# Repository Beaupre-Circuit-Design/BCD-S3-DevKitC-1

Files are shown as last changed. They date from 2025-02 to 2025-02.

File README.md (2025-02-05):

# BCD-S3-DevKitC-1

ESP32-S3-WROOM-1-N16R8 Development Board

## Description

An ESP32-S3 development board based on Espressif's ESP32-S3-DevKitC-1.

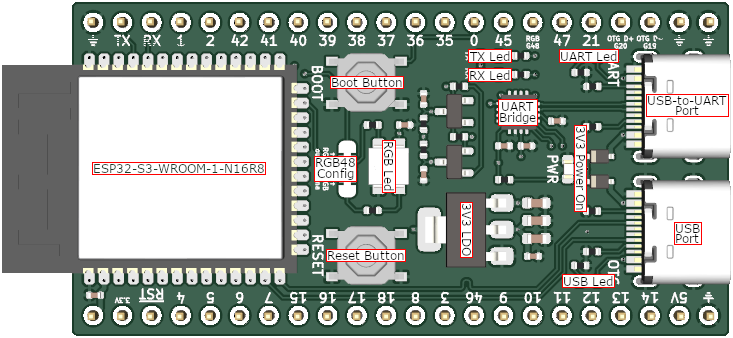
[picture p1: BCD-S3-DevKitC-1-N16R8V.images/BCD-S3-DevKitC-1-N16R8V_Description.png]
Board Description


|Key Component |Description |
|---|---|
|ESP32-S3-WROOM-1-N16R8|ESP32-S3R8 with 3.3V, 8 MB Octal PSRAM die inside, 16 MB Quad SPI flash, PCB antenna.[^1]|
|3V3 LDO |Power regulator that converts a 5 V supply into a 3.3 V output.|
|Boot Button |Holding down Boot and then pressing Reset initiates Firmware Download mode for downloading firmware through the serial port.|
|Reset Button |Press this button to restart the system.|
|RGB48 Config |Configuration options for the RGB Led / GPIO 48.|
|USB-to-Uart Port |A Micro-USB port used for power supply to the board, for flashing applications to the chip, as well as for communication with the chip via the on-board USB-to-UART bridge.|
|USB Port |ESP32-S3 full-speed USB OTG interface, compliant with the USB 1.1 specification. The interface is used for power supply to the board, for flashing applications to the chip, for communication with the chip using USB 1.1 protocols, as well as for JTAG debugging.|
|UART Led |Indicate if the USB-to-UART port is connected.|
|USB Led |Indicate if the USB port is connected.|
|3V3 Power On |Indicate if the 3V3 bus is powered.|
|TX Led |Indicate if the serial bus is transmitting.|
|RX Led |Indicate if the serial bus is receiving.|
|RGB Led |Addressable RGB LED, driven by GPIO48.|

[^1]: GPIO35, GPIO36 and GPIO37 are used for the internal communication between ESP32-S3 and SPI flash/PSRAM memory, thus not available for external use.

## Pinout

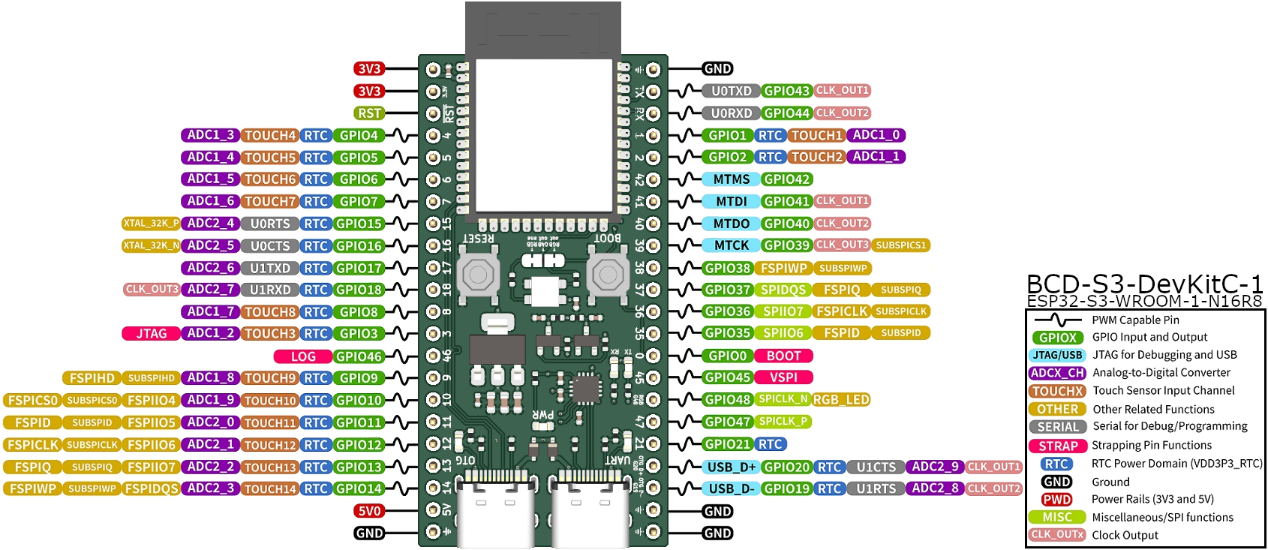
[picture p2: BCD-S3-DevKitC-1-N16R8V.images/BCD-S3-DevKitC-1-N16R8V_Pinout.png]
Board Pinout


## RGB48 Jumper

|Jumper|Effect|
|---|---|
|Default|Default Configuration, RGB48 pin is the output of the RGBLed.|
|Mode 1|RGB48 pin is the output of GPIO48, Led is still active and drive by GPIO48. [^2]|
|Mode 2|RGB48 pin is the output of GPIO48, Led is deactivated. [^2][^3]|

[^2]: If the output of the RGBLed is still needed, a wire can be soldered to the leftmost pad.
[^3]: The RGBLed can still be driven by soldering a wire to the rightmost pad.

## Bulding / Ordering PCB

The [board layout](BCD-S3-DevKitC-1-N16R8V.production/gerber) and [bill of material](BCD-S3-DevKitC-1-N16R8V.production/assembly) has been optimised for JLCPCB's capabilities and inventories to minimise cost. The footprint for the ESP32-S3 module has been optimised for hand-soldering since this part alone greatly increase the price of the assembly.

## Version History

* 1.1(2025-02-02)
    * Fix error in RGB48 Jumper.
* 1.0(2025-01-05)
    * Initial Release.

## License

This project is licensed under the [BSD 3-Clause License](LICENSE).

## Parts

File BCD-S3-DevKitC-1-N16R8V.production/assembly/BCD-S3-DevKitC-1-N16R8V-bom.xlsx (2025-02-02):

Reference | Value | Datasheet | Footprint | Qty | DNP | JLCPCB | Manufacturer | PartNumber | Description
C1,C3,C9,C11 | 1uF | https://www.lcsc.com/datasheet/lcsc_datasheet_2304140030_Samsung-Electro-Mechanics-CL05A105KA5NQNC_C52923.pdf | BCD-S3-DevKitC-1-N16R8V:C_0402_1005Metric | 4 | False | C52923 | Samsung Electro-Mechanics | CL05A105KA5NQNC | 25V 1uF X5R ±10% 0402 Multilayer Ceramic Capacitors MLCC - SMD/SMT ROHS
C2,C4,C5,C10 | 100nF | https://www.lcsc.com/datasheet/lcsc_datasheet_2304140030_Samsung-Electro-Mechanics-CL05B104KO5NNNC_C1525.pdf | BCD-S3-DevKitC-1-N16R8V:C_0402_1005Metric | 4 | False | C1525 | Samsung Electro-Mechanics | CL05B104KO5NNNC | 16V 100nF X7R ±10% 0402 Multilayer Ceramic Capacitors MLCC - SMD/SMT ROHS
C6,C7,C8 | 10uF | https://www.lcsc.com/datasheet/lcsc_datasheet_2304140030_Samsung-Electro-Mechanics-CL10A106MA8NRNC_C96446.pdf | BCD-S3-DevKitC-1-N16R8V:C_0603_1608Metric | 3 | False | C96446 | Samsung Electro-Mechanics | CL10A106MA8NRNC | 25V 10uF X5R ±20% 0603 Multilayer Ceramic Capacitors MLCC - SMD/SMT ROHS
D1,D2 | 1N5819WS | https://www.lcsc.com/datasheet/lcsc_datasheet_2409300937_Guangdong-Hottech-1N5819WS_C191023.pdf | BCD-S3-DevKitC-1-N16R8V:D_SOD-323 | 2 | False | C191023 | Guangdong Hottech | 1N5819WS | 40V 600mV@1A 1A SOD-323 Schottky Diodes ROHS
D3,D4,D5,D7,D8 | RED | https://www.lcsc.com/datasheet/lcsc_datasheet_1810231112_Hubei-KENTO-Elec-KT-0603R_C2286.pdf | BCD-S3-DevKitC-1-N16R8V:LED_0603_1608Metric | 5 | False | C2286 | Hubei KENTO Elec | KT-0603R | Red 0603 LED Indication - Discrete ROHS
D6 | SK6812MINI-HS | https://www.lcsc.com/datasheet/lcsc_datasheet_2412101523_OPSCO-Optoelectronics-SK6812MINI-HS_C2922787.pdf | BCD-S3-DevKitC-1-N16R8V:SK6812MINI-HS | 1 | False | C2922787 | OPSCO Optoelectronics | SK6812MINI-HS | SMD,3.5x3.7mm RGB LEDs(Built-in IC) ROHS
Q1,Q2 | SS8050 | https://www.lcsc.com/datasheet/lcsc_datasheet_2303221100_Jiangsu-Changjing-Electronics-Technology-Co---Ltd--SS8050-RANGE-200-350_C2150.pdf | BCD-S3-DevKitC-1-N16R8V:SOT-23 | 2 | False | C2150 | Jiangsu Changjing Electronics Technology Co., Ltd. | SS8050(RANGE:200-350) | General Purpose NPN Transistor, 1.5A Ic, 25V Vce, SOT-23
R1,R2,R3,R4 | 5.1kΩ | https://www.lcsc.com/datasheet/lcsc_datasheet_2206010045_UNI-ROYAL-Uniroyal-Elec-0402WGF5101TCE_C25905.pdf | BCD-S3-DevKitC-1-N16R8V:R_0402_1005Metric | 4 | False | C25905 | UNI-ROYAL(Uniroyal Elec) | 0402WGF5101TCE | 62.5mW Thick Film Resistors 50V ±100ppm/℃ ±1% 5.1kΩ 0402 Chip Resistor - Surface Mount ROHS
R5,R6,R11,R12,R13,R14,R15 | 510Ω | https://www.lcsc.com/datasheet/lcsc_datasheet_2205311900_UNI-ROYAL-Uniroyal-Elec-0402WGF5100TCE_C25123.pdf | BCD-S3-DevKitC-1-N16R8V:R_0402_1005Metric | 7 | False | C25123 | UNI-ROYAL(Uniroyal Elec) | 0402WGF5100TCE | 62.5mW Thick Film Resistors 50V ±100ppm/℃ ±1% 510Ω 0402 Chip Resistor - Surface Mount ROHS
R7,R8,R9,R10 | 10kΩ | https://www.lcsc.com/datasheet/lcsc_datasheet_2411221126_UNI-ROYAL-Uniroyal-Elec-0402WGF1002TCE_C25744.pdf | BCD-S3-DevKitC-1-N16R8V:R_0402_1005Metric | 4 | False | C25744 | UNI-ROYAL(Uniroyal Elec) | 0402WGF1002TCE | 62.5mW Thick Film Resistors 50V ±100ppm/℃ ±1% 10kΩ 0402 Chip Resistor - Surface Mount ROHS
SW1 | BOOT | https://www.lcsc.com/datasheet/lcsc_datasheet_2304140030_XKB-Connection-TS-1187A-B-A-B_C318884.pdf | BCD-S3-DevKitC-1-N16R8V:SW_Push_1P1T_XKB_TS-1187A | 1 | False | C318884 | XKB Connection | TS-1187A-B-A-B | None Without 50mA 5.1mm 100000 Times 160gf 12V 5.1mm 1.5mm Round Button Standing paste SPST SMD Tactile Switches ROHS
SW2 | RESET | https://www.lcsc.com/datasheet/lcsc_datasheet_2304140030_XKB-Connection-TS-1187A-B-A-B_C318884.pdf | BCD-S3-DevKitC-1-N16R8V:SW_Push_1P1T_XKB_TS-1187A | 1 | True | C318884 | XKB Connection | TS-1187A-B-A-B | None Without 50mA 5.1mm 100000 Times 160gf 12V 5.1mm 1.5mm Round Button Standing paste SPST SMD Tactile Switches ROHS
U1 | ESP32-S3-WROOM-1 | https://www.lcsc.com/datasheet/lcsc_datasheet_2411121101_Espressif-Systems-ESP32-S3-WROOM-1-N16R8_C2913202.pdf | BCD-S3-DevKitC-1-N16R8V:ESP32-S3-WROOM-1 | 1 | False | C2913202 | Espressif Systems | ESP32-S3-WROOM-1-N16R8 | RF Module, ESP32-S3 SoC, Wi-Fi 802.11b/g/n, Bluetooth, BLE, 32-bit, 3.3V, onboard antenna, SMD
U2 | AMS1117-3.3 | https://www.lcsc.com/datasheet/lcsc_datasheet_2304140030_Advanced-Monolithic-Systems-AMS1117-3-3_C6186.pdf | BCD-S3-DevKitC-1-N16R8V:SOT-223-3_TabPin2 | 1 | False | C6186 | Advanced Monolithic Systems | AMS1117-3.3 | 1A Low Dropout regulator, positive, 3.3V fixed output, SOT-223
U3 | CH343P | https://www.lcsc.com/datasheet/lcsc_datasheet_2403131129_WCH-Jiangsu-Qin-Heng-CH343P_C2846043.pdf | BCD-S3-DevKitC-1-N16R8V:QFN-16-1EP_3x3mm_P0.5mm_EP1.7x1.7mm | 1 | False | C2846043 | WCH(Jiangsu Qin Heng) | CH343P | USB serial converter, UART, TQFN-16-EP
USB1 | UART | https://www.lcsc.com/datasheet/lcsc_datasheet_2410010003_Korean-Hroparts-Elec-TYPE-C-31-M-12_C165948.pdf | BCD-S3-DevKitC-1-N16R8V:USB_C_Receptacle_HRO_TYPE-C-31-M-12 | 1 | False | C165948 | Korean Hroparts Elec | TYPE-C-31-M-12 | USB 2.0-only 16P Type-C Receptacle connector
USB2 | USB-OTG | https://www.lcsc.com/datasheet/lcsc_datasheet_2410010003_Korean-Hroparts-Elec-TYPE-C-31-M-12_C165948.pdf | BCD-S3-DevKitC-1-N16R8V:USB_C_Receptacle_HRO_TYPE-C-31-M-12 | 1 | False | C165948 | Korean Hroparts Elec | TYPE-C-31-M-12 | USB 2.0-only 16P Type-C Receptacle connector

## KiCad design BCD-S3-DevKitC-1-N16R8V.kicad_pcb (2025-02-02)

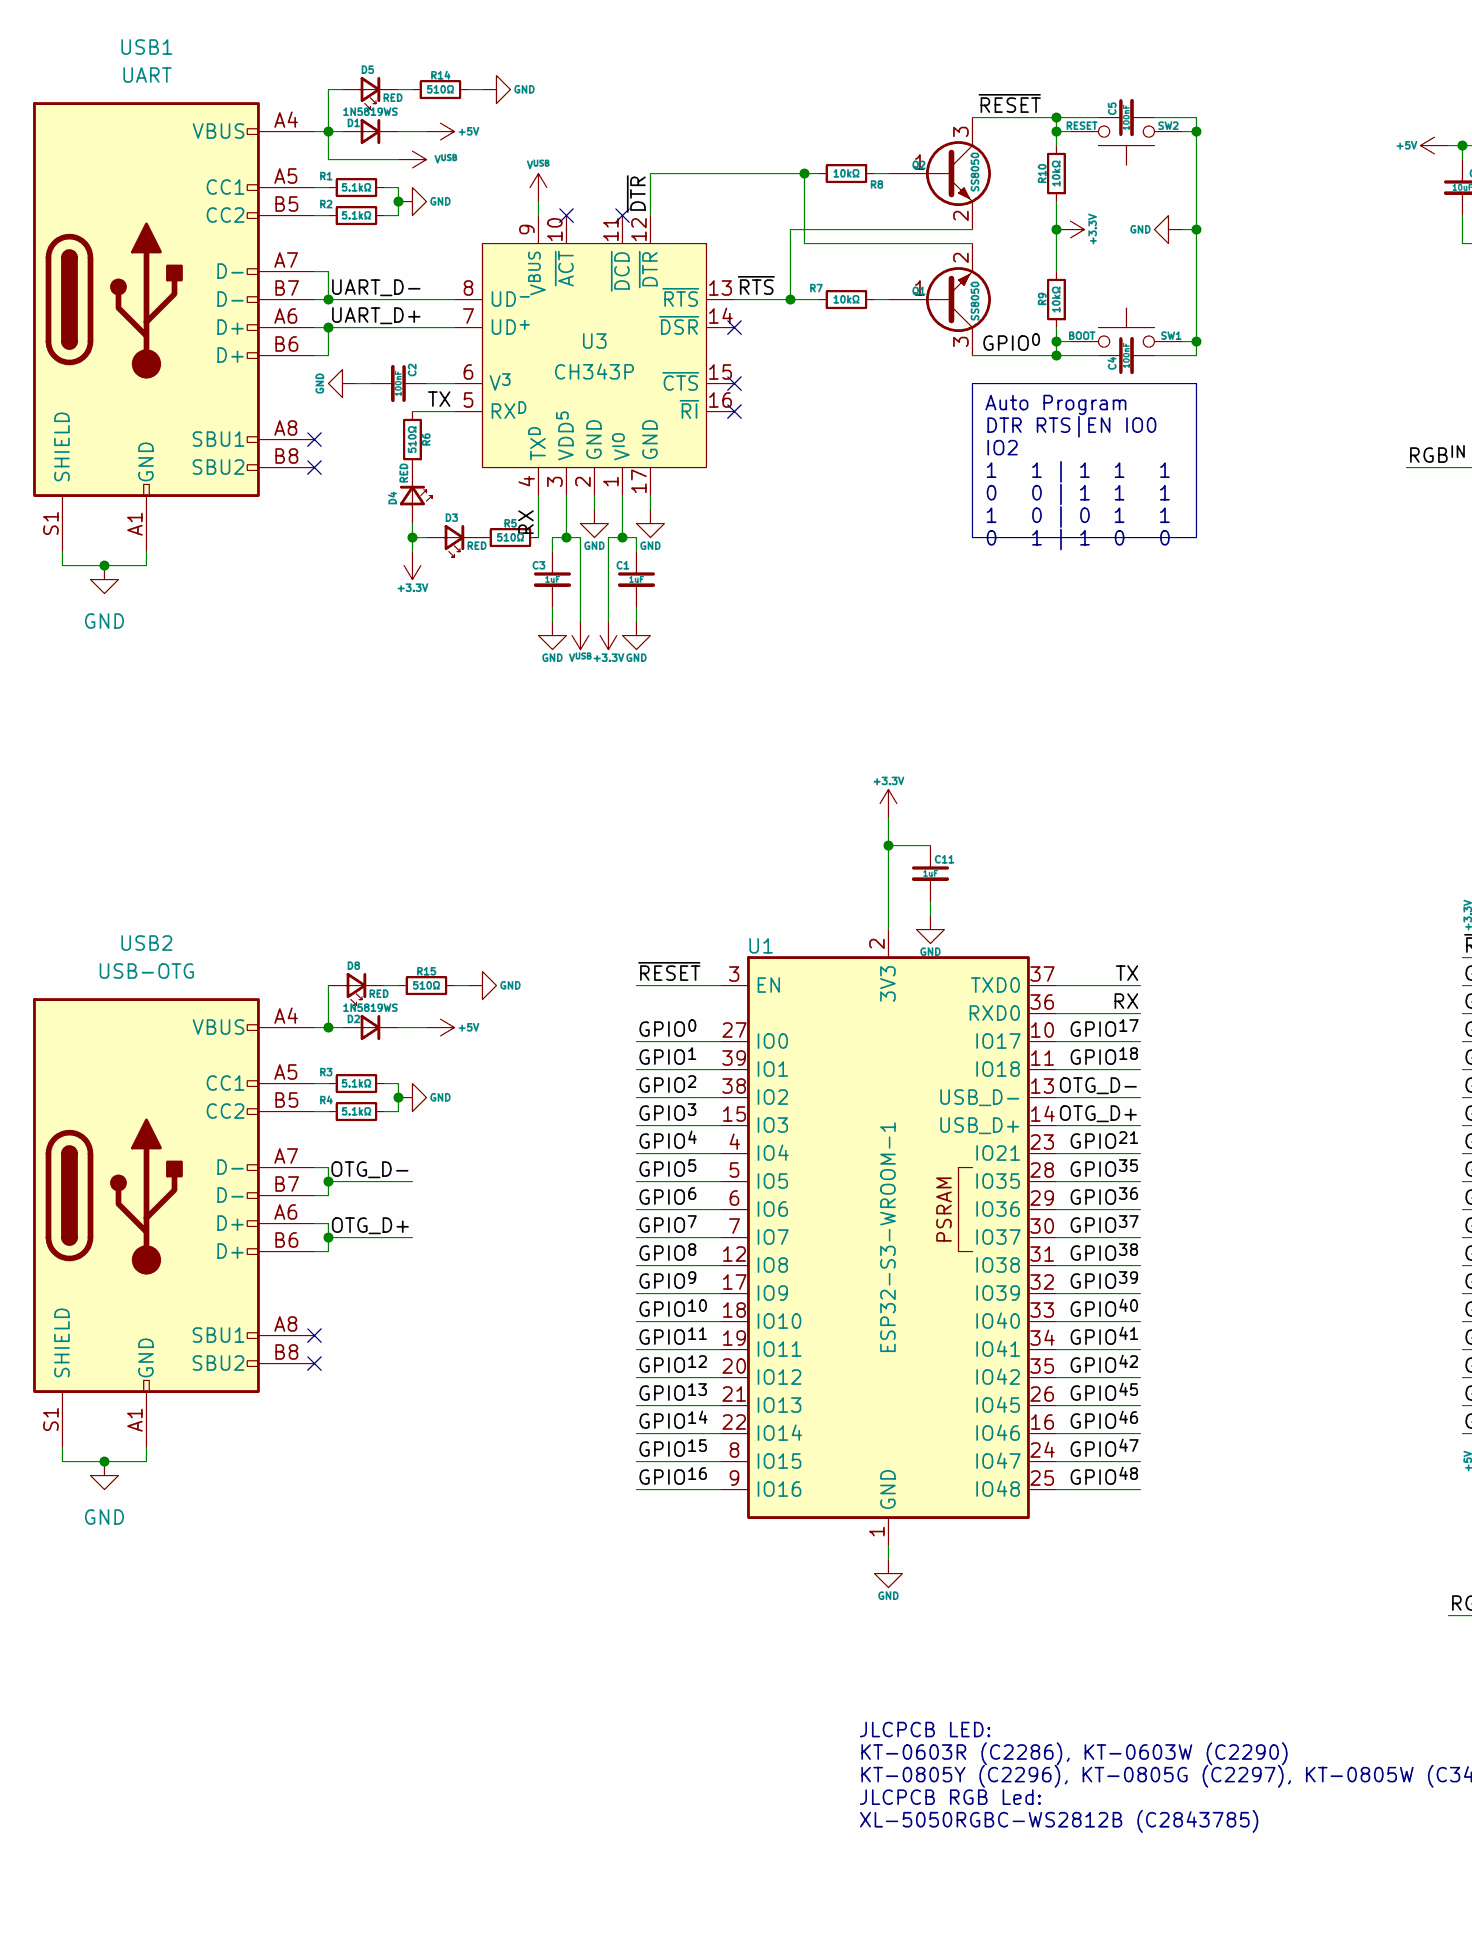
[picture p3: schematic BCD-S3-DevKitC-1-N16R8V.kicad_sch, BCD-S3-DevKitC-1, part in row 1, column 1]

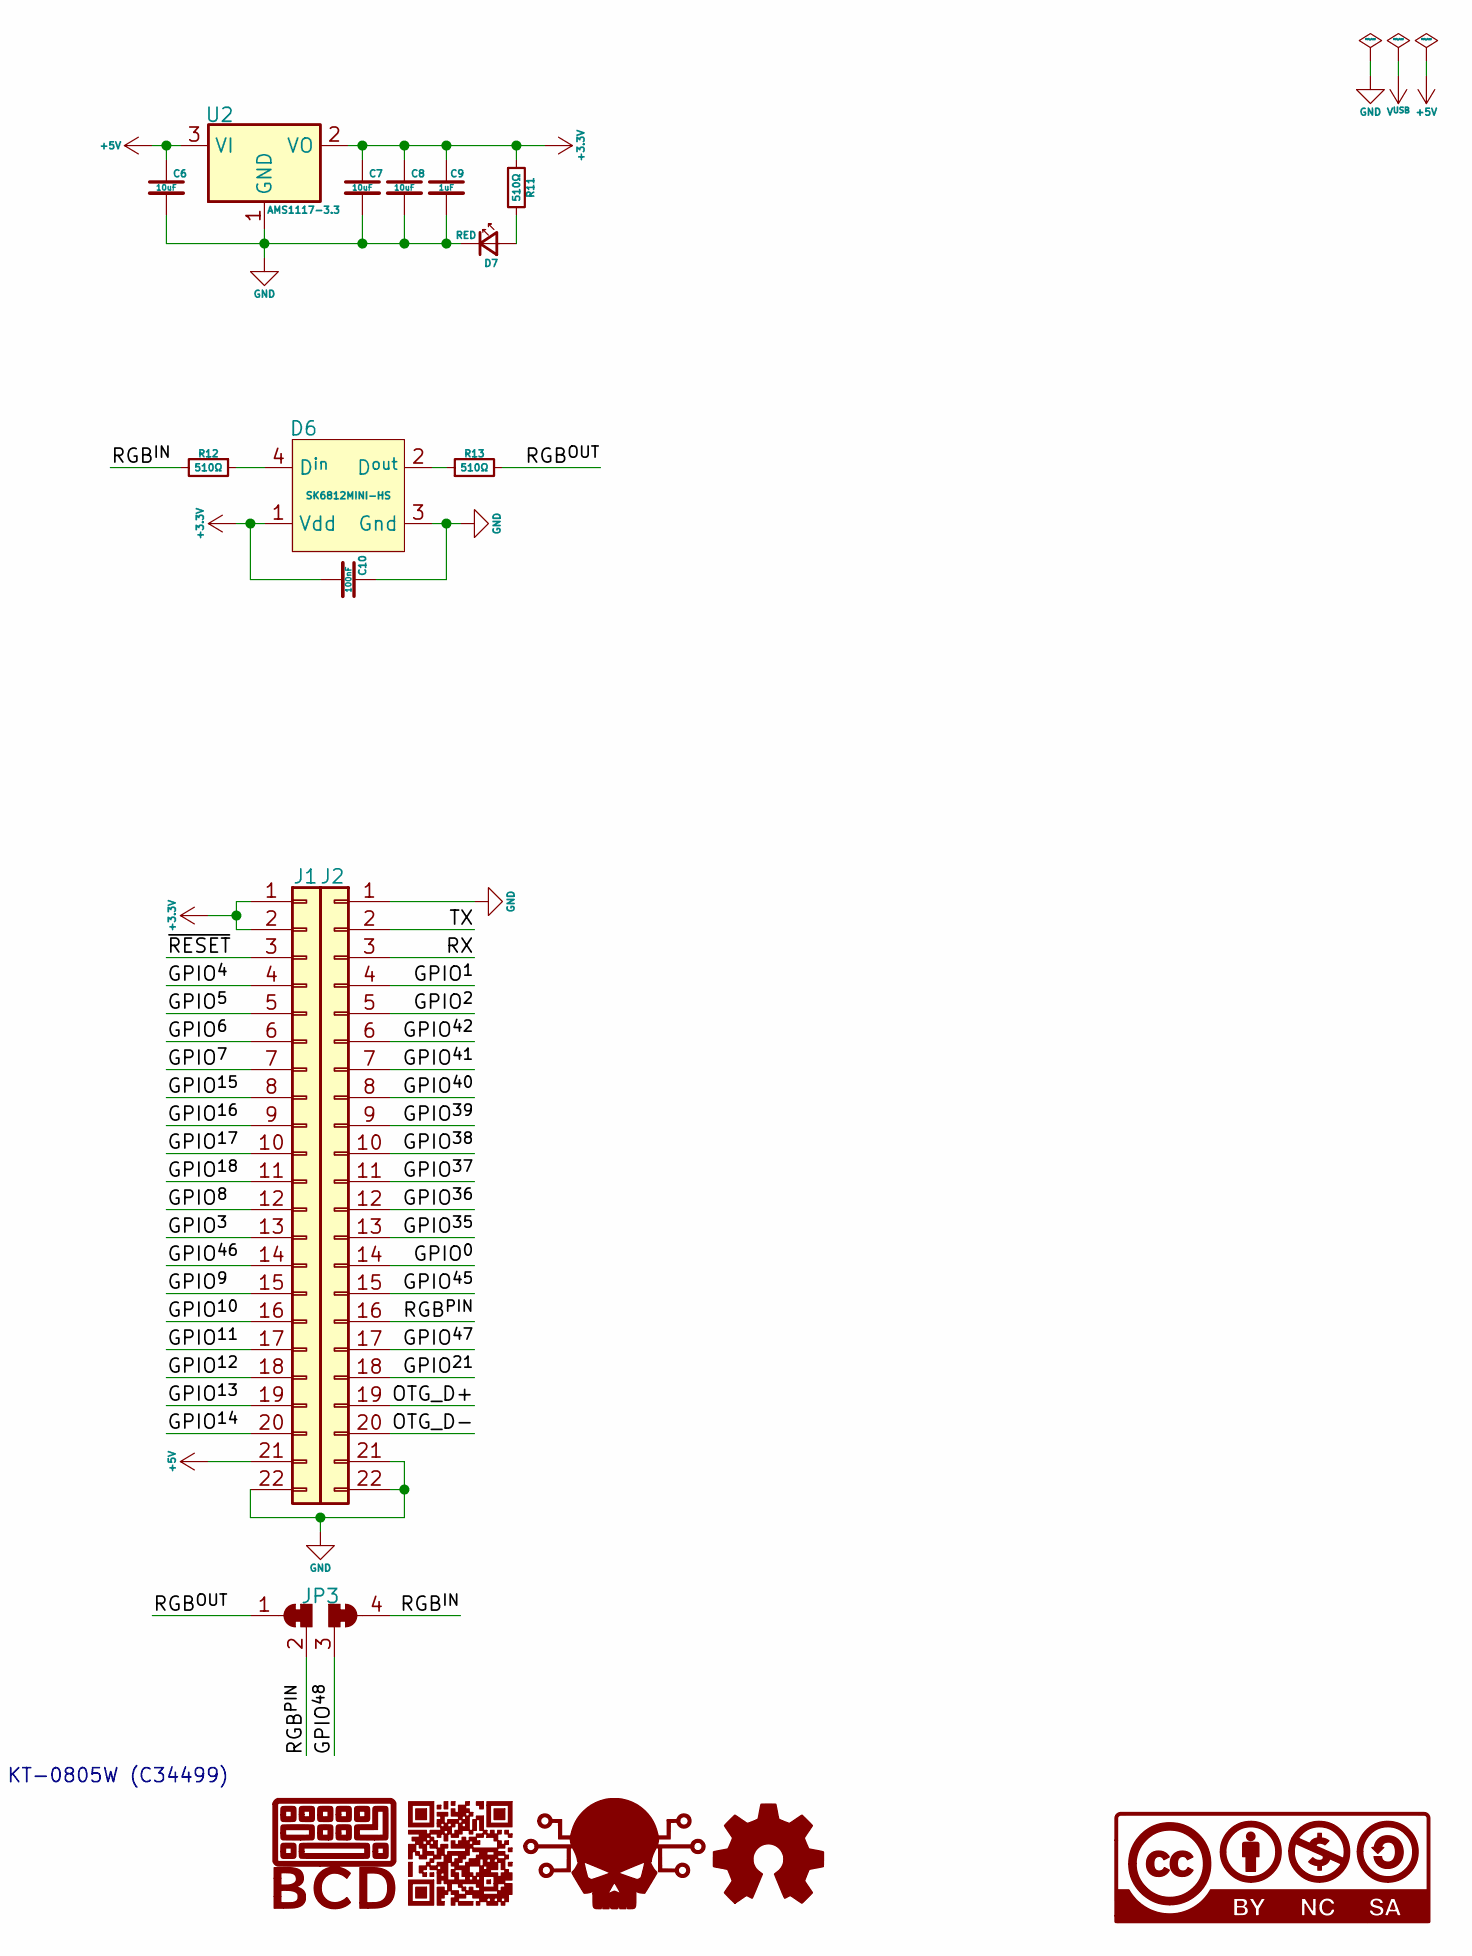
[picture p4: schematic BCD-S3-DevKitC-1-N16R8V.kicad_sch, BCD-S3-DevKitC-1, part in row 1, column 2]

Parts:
C1, C3, C9, C11: 1uF; C_0402_1005Metric; PartNumber CL05A105KA5NQNC; JLCPCB C52923
C2, C4, C5, C10: 100nF; C_0402_1005Metric; PartNumber CL05B104KO5NNNC; JLCPCB C1525
C6, C7, C8: 10uF; C_0603_1608Metric; PartNumber CL10A106MA8NRNC; JLCPCB C96446
D1, D2: 1N5819WS; D_SOD-323; PartNumber 1N5819WS; JLCPCB C191023
D3, D4, D5, D7, D8: RED; LED_0603_1608Metric; PartNumber KT-0603R; JLCPCB C2286
D6: SK6812MINI-HS; PartNumber SK6812MINI-HS; JLCPCB C2922787
G1: BCD_Logo; BCD_Logo_2.5mm
G2: BDC_QR; BCD-S3-DevKitC-1_5mm
G3: Skull; Skull_2.5mm
G4: OpenSource_Hardware; Open_Source_Hardware_2.5mm
G5: CC-BY-NC-SA; cc-by-nc-sa_2.5mm
J1, J2: Conn_01x22; PinHeader_1x22_P2.54mm_Vertical
JP3: SolderJumper_4_Bridged12_34; SolderJumper-4_P1.3mm_Bridged12_34_RoundedPad1.0x1.5mm_1
Q1, Q2: SS8050; SOT-23; PartNumber SS8050(RANGE:200-350); JLCPCB C2150
R1, R2, R3, R4: 5.1kΩ; R_0402_1005Metric; PartNumber 0402WGF5101TCE; JLCPCB C25905
R5, R6, R11, R12, R13, R14, R15: 510Ω; R_0402_1005Metric; PartNumber 0402WGF5100TCE; JLCPCB C25123
R7, R8, R9, R10: 10kΩ; R_0402_1005Metric; PartNumber 0402WGF1002TCE; JLCPCB C25744
SW1: BOOT; SW_Push_1P1T_XKB_TS-1187A; PartNumber TS-1187A-B-A-B; JLCPCB C318884
SW2: RESET; SW_Push_1P1T_XKB_TS-1187A; PartNumber TS-1187A-B-A-B; JLCPCB C318884
U1: ESP32-S3-WROOM-1; ESP32-S3-WROOM-1_HandSolder; PartNumber ESP32-S3-WROOM-1-N16R8; JLCPCB C2913202
U2: AMS1117-3.3; SOT-223-3_TabPin2; PartNumber AMS1117-3.3; JLCPCB C6186
U3: CH343P; QFN-16-1EP_3x3mm_P0.5mm_EP1.7x1.7mm; PartNumber CH343P; JLCPCB C2846043
USB1: UART; USB_C_Receptacle_HRO_TYPE-C-31-M-12; PartNumber TYPE-C-31-M-12; JLCPCB C165948
USB2: USB-OTG; USB_C_Receptacle_HRO_TYPE-C-31-M-12; PartNumber TYPE-C-31-M-12; JLCPCB C165948

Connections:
+3.3V: C1.1, C7.1, C8.1, C9.1, C10.2, C11.1, D3.2 (A), D4.2 (A), D6.1 (Vdd), J1.1, J1.2, R9.2, R10.1, R11.1, U1.2 (3V3), U2.2 (VO), U3.1 (V^{IO})
+5V: C6.1, D1.1 (K), D2.1 (K), J1.21, U2.3 (VI)
/GPIO^{0}: C4.1, J2.14, Q1.3 (C), R9.1, SW1.2, U1.27 (IO0)
/GPIO^{1}: J2.4, U1.39 (IO1)
/GPIO^{2}: J2.5, U1.38 (IO2)
/GPIO^{3}: J1.13, U1.15 (IO3)
/GPIO^{4}: J1.4, U1.4 (IO4)
/GPIO^{5}: J1.5, U1.5 (IO5)
/GPIO^{6}: J1.6, U1.6 (IO6)
/GPIO^{7}: J1.7, U1.7 (IO7)
/GPIO^{8}: J1.12, U1.12 (IO8)
/GPIO^{9}: J1.15, U1.17 (IO9)
/GPIO^{10}: J1.16, U1.18 (IO10)
/GPIO^{11}: J1.17, U1.19 (IO11)
/GPIO^{12}: J1.18, U1.20 (IO12)
/GPIO^{13}: J1.19, U1.21 (IO13)
/GPIO^{14}: J1.20, U1.22 (IO14)
/GPIO^{15}: J1.8, U1.8 (IO15)
/GPIO^{16}: J1.9, U1.9 (IO16)
/GPIO^{17}: J1.10, U1.10 (IO17)
/GPIO^{18}: J1.11, U1.11 (IO18)
/GPIO^{21}: J2.18, U1.23 (IO21)
/GPIO^{35}: J2.13, U1.28 (IO35)
/GPIO^{36}: J2.12, U1.29 (IO36)
/GPIO^{37}: J2.11, U1.30 (IO37)
/GPIO^{38}: J2.10, U1.31 (IO38)
/GPIO^{39}: J2.9, U1.32 (IO39)
/GPIO^{40}: J2.8, U1.33 (IO40)
/GPIO^{41}: J2.7, U1.34 (IO41)
/GPIO^{42}: J2.6, U1.35 (IO42)
/GPIO^{45}: J2.15, U1.26 (IO45)
/GPIO^{46}: J1.14, U1.16 (IO46)
/GPIO^{47}: J2.17, U1.24 (IO47)
/GPIO^{48}: JP3.3 (D), U1.25 (IO48)
/OTG_D+: J2.19, U1.14 (USB_D+), USB2.A6 (D+), USB2.B6 (D+)
/OTG_D-: J2.20, U1.13 (USB_D-), USB2.A7 (D-), USB2.B7 (D-)
/RGB^{IN}: JP3.4 (B), R12.2
/RGB^{OUT}: JP3.1 (A), R13.2
/RGB^{PIN}: J2.16, JP3.2 (C)
/RX: J2.3, R5.2, U1.36 (RXD0), U3.4 (TX^{D})
/TX: J2.2, R6.2, U1.37 (TXD0), U3.5 (RX^{D})
/UART_D+: U3.7 (UD^{+}), USB1.A6 (D+), USB1.B6 (D+)
/UART_D-: U3.8 (UD^{-}), USB1.A7 (D-), USB1.B7 (D-)
/~DTR: Q1.2 (E), R8.2, U3.12 (~DTR)
/~RESET: C5.1, J1.3, Q2.3 (C), R10.2, SW2.2, U1.3 (EN)
/~RTS: Q2.2 (E), R7.1, U3.13 (~RTS)
GND: C1.2, C2.2, C3.2, C4.2, C5.2, C6.2, C7.2, C8.2, C9.2, C10.1, C11.2, D6.3 (Gnd), D7.1 (K), J1.22, J2.1, J2.21, J2.22, R1.2, R2.2, R3.2, R4.2, R14.2, R15.2, SW1.1, SW2.1, U1.1 (GND), U1.40 (GND), U1.41 (GND), U2.1 (GND), U3.2 (GND), U3.17 (GND), USB1.A1 (GND), USB1.A12 (GND), USB1.B1 (GND), USB1.B12 (GND), USB1.S1 (SHIELD), USB2.A1 (GND), USB2.A12 (GND), USB2.B1 (GND), USB2.B12 (GND), USB2.S1 (SHIELD)
unnamed: D2.2 (A), D8.2 (A), USB2.A4 (VBUS), USB2.A9 (VBUS), USB2.B4 (VBUS), USB2.B9 (VBUS)
unnamed: D3.1 (K), R5.1
unnamed: D4.1 (K), R6.1
unnamed: D5.1 (K), R14.1
unnamed: D6.4 (D^{in}), R12.1
unnamed: D6.2 (D^{out}), R13.1
unnamed: D7.2 (A), R11.2
unnamed: D8.1 (K), R15.1
unnamed: Q1.1 (B), R7.2
unnamed: Q2.1 (B), R8.1
unnamed: C2.1, U3.6 (V^{3})
unnamed: R1.1, USB1.A5 (CC1)
unnamed: R2.1, USB1.B5 (CC2)
unnamed: R3.1, USB2.A5 (CC1)
unnamed: R4.1, USB2.B5 (CC2)
V^{USB}: C3.1, D1.2 (A), D5.2 (A), U3.3 (VDD^{5}), U3.9 (V^{BUS}), USB1.A4 (VBUS), USB1.A9 (VBUS), USB1.B4 (VBUS), USB1.B9 (VBUS)

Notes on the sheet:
Auto Program DTR RTS|EN IO0 IO2 1 1 | 1 1 1 0 0 | 1 1 1 1 0 | 0 1 1 0 1 | 1 0 0
JLCPCB LED: KT-0603R (C2286), KT-0603W (C2290) KT-0805Y (C2296), KT-0805G (C2297), KT-0805W (C34499) JLCPCB RGB Led: XL-5050RGBC-WS2812B (C2843785)

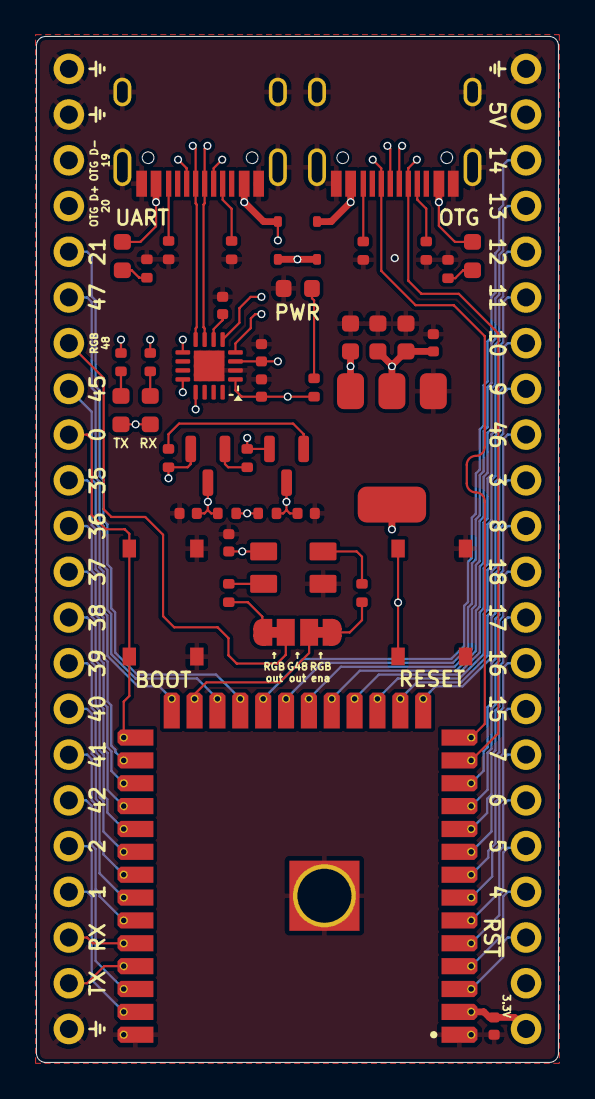
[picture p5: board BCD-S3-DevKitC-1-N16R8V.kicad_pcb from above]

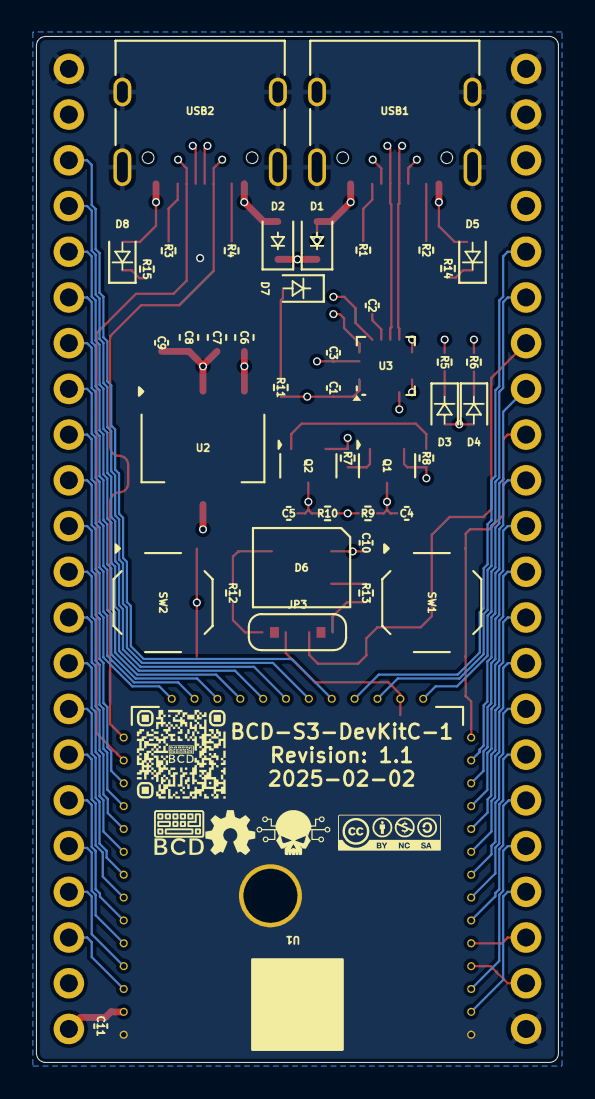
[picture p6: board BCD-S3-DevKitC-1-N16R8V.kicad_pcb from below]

Board: 4 copper layers, 29.0 x 57.0 mm, 51 parts (7 on the bottom side), 63 nets.

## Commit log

2025-02-02 Initial Release
    [BCD-S3-DevKitC-1-N16R8V-B_Cu.gbl, BCD-S3-DevKitC-1-N16R8V-B_Mask.gbs, BCD-S3-DevKitC-1-N16R8V-B_Paste.gbp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]
2025-02-02 Add help for RGB48 jumper. Fixed error in PCB for RGB48.
    [BCD-S3-DevKitC-1-N16R8V-B_Cu.gbl, BCD-S3-DevKitC-1-N16R8V-B_Mask.gbs, BCD-S3-DevKitC-1-N16R8V-B_Paste.gbp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]
